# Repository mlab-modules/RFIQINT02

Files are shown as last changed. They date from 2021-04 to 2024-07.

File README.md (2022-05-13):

# RFIQINT02B -  RF signal I/Q interface

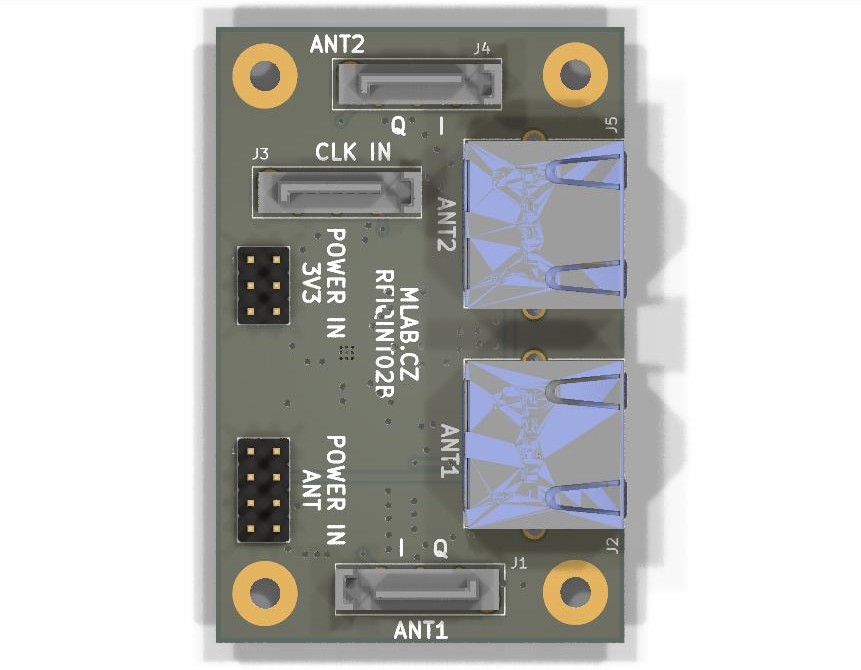
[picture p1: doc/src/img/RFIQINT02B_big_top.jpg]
RFIQINT02B PCB render


## Parameters

| Parameter | Value | Description |
|---|---|---|
| Frequency range | 100 - 1000 MHz |  |
| Interface | RJ45 | CAT 7/A cable is expected |
| Operating and storage temperature | -20 - +30°C |  |
| Operational input voltage for Antenna | 9 - 12 V |  |
| Operational input voltage  | 3.3-3.6 V | 130 mA for LO buffer core |

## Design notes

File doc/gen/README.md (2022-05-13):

# PCB

Board size: 40.13x60.45 mm (1.58x2.38 inches)

- This is the size of the rectangle that contains the board
- Thickness: 1.6 mm (63 mils)
- Material: FR4
- Finish: None
- Layers: 2
- Copper thickness: 35 µm

Solder mask: TOP / BOTTOM

- Color: Green

Silk screen: TOP / BOTTOM

- Color: White

Stackup:

| Name | Type | Color | Thickness | Material | Epsilon_r | Loss tangent |
|---|---|---|---|---|---|---|
| F.SilkS | Top Silk Screen | | | | | |
| F.Paste | Top Solder Paste | | | | | |
| F.Mask | Top Solder Mask | Green | 10 | | | |
| F.Cu | copper | | 35 | | | |
| dielectric 1 | core | | 1510 | FR4 | 4.5 | 0.02 |
| B.Cu | copper | | 35 | | | |
| B.Mask | Bottom Solder Mask | Green | 10 | | | |
| B.Paste | Bottom Solder Paste  | | | | | |
| B.SilkS | Bottom Silk Screen | | | | | |

# Important sizes

Clearance: 0.2 mm (8 mils)

Track width: 0.2 mm (8 mils)

- By design rules: 0.15 mm (6 mils)

Drill: 0.3 mm (12 mils)

- Vias: 0.4 mm (16 mils) [Design: 0.3 mm (12 mils)]
- Pads: 0.3 mm (12 mils)

Via: 0.8/0.4 mm (31/16 mils)

- By design rules: 0.4/0.3 mm (16/12 mils)
- Micro via: no [0.2/0.1 mm (8/4 mils)]
- Burried/blind via: no

Outer Annular Ring: 0.2 mm (8 mils)

- By design rules: 0.3 mm (12 mils)

Eurocircuits class: 4C

# General stats

Components count: (SMD/THT)

- Top: 0/9 (THT)
- Bottom: 35/2 (SMD + THT)

Defined tracks:

- 0.15 mm (6 mils)
- 0.2 mm (8 mils)
- 0.3 mm (12 mils)
- 0.4 mm (16 mils)
- 0.5 mm (20 mils)

Used tracks:

- 0.2 mm (8 mils) (22) defined: yes
- 0.3 mm (12 mils) (290) defined: yes
- 0.4 mm (16 mils) (28) defined: yes
- 0.5 mm (20 mils) (30) defined: yes
- 0.7 mm (28 mils) (26) defined: no

Defined vias:

Used vias:

- 0.8/0.4 mm (31/16 mils) (Count: 5, Aspect: 2.0 A) defined: no
- 0.8/0.6 mm (31/24 mils) (Count: 73, Aspect: 2.0 A) defined: no

Holes (excluding vias):

- 0.3 mm (12 mils) (9)
- 0.74 mm (29 mils) (21)
- 0.89 mm (35 mils) (14)
- 0.93 mm (37 mils) (24)
- 1.35 mm (53 mils) (6)
- 1.65 mm (65 mils) (4)
- 3.0 mm (118 mils) (4)
- 3.3 mm (130 mils) (4)

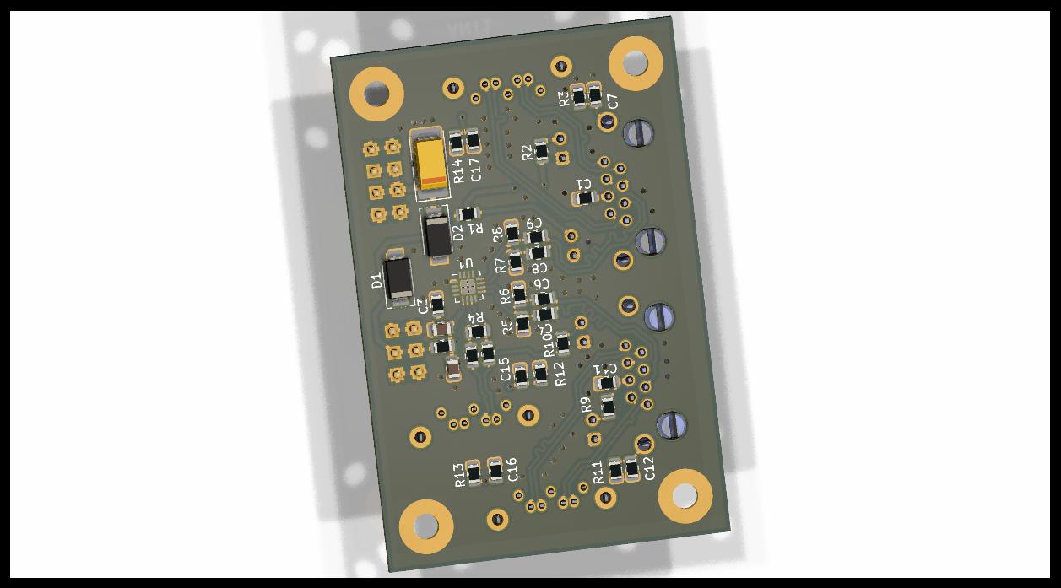
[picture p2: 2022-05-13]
doc/src/img/RFIQINT02B_big_bot.jpg

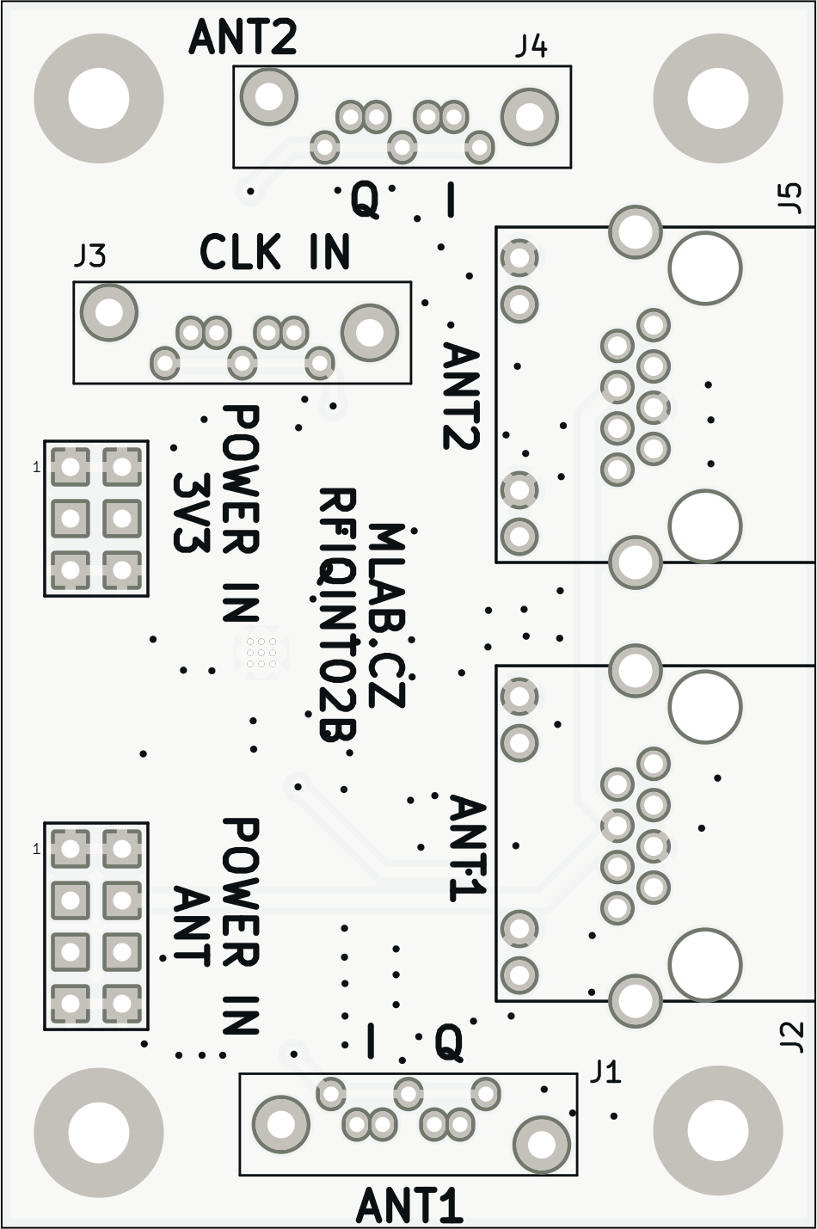
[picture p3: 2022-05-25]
doc/gen/img/RFIQINT02B-top.png

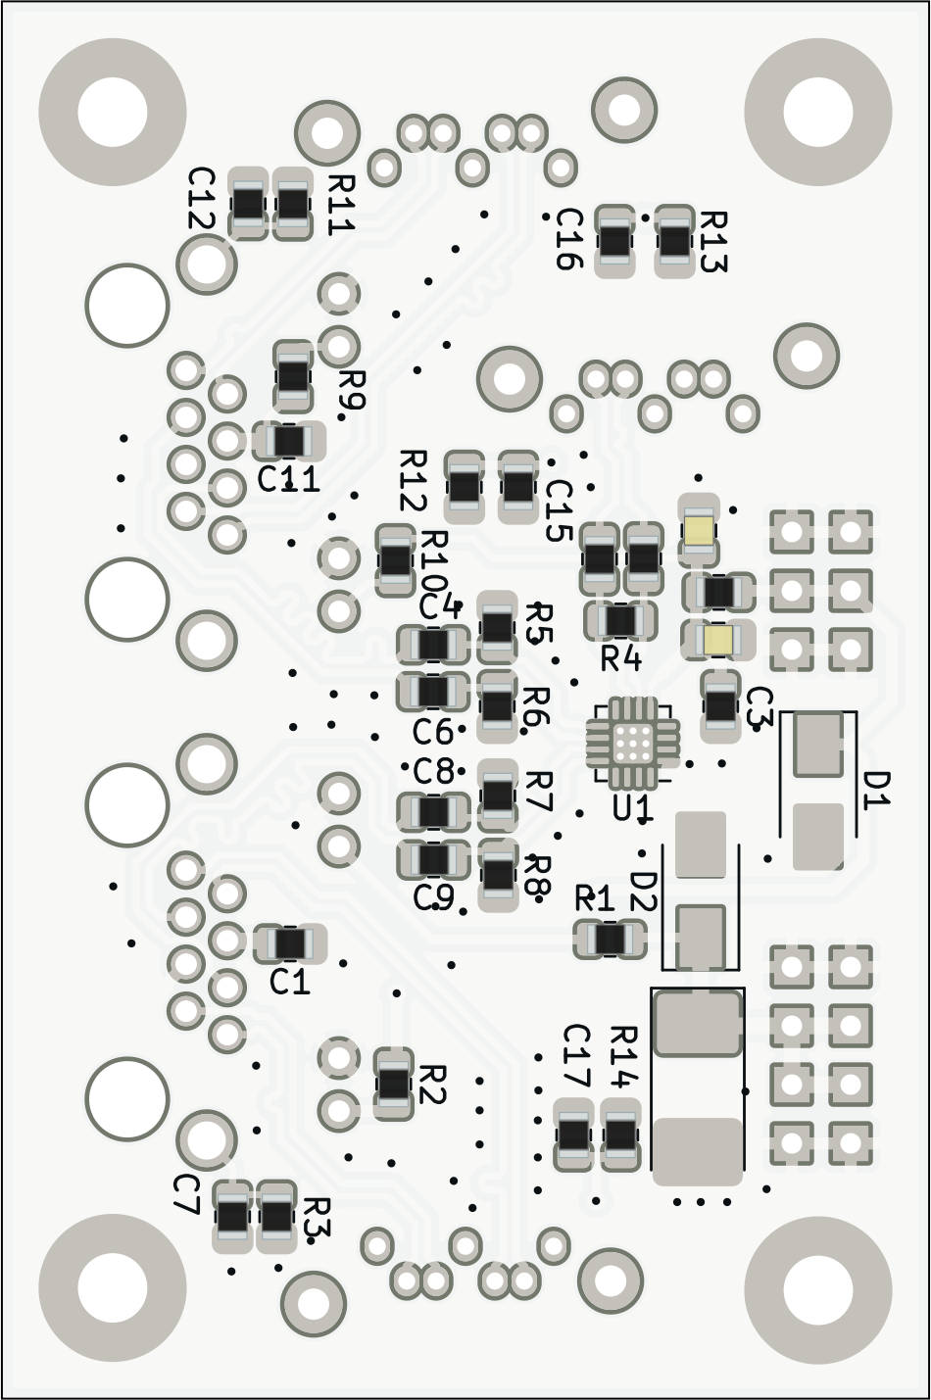
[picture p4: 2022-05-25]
doc/gen/img/RFIQINT02B-bottom.png

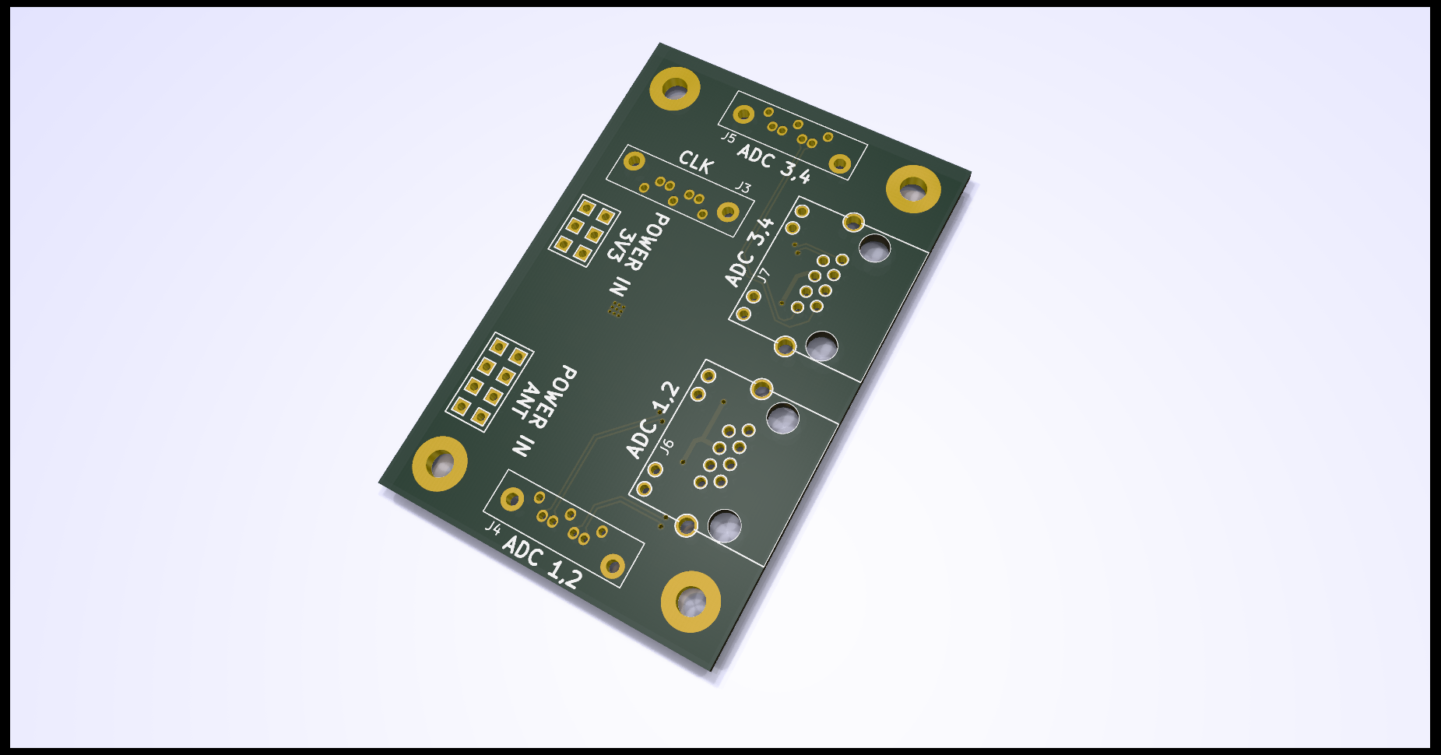
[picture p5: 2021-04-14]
doc/src/img/RFIQINT02A_PCB_render.png

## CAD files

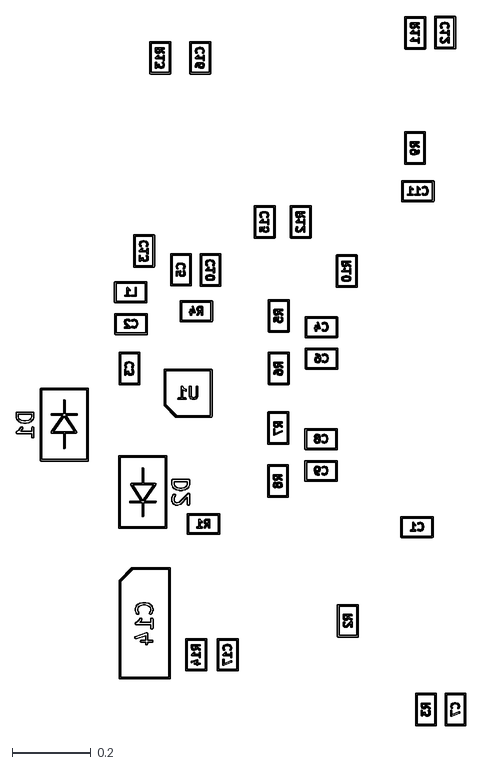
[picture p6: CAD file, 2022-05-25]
doc/gen/dxf/RFIQINT02B-B_Fab.dxf
1.15 x 1.81

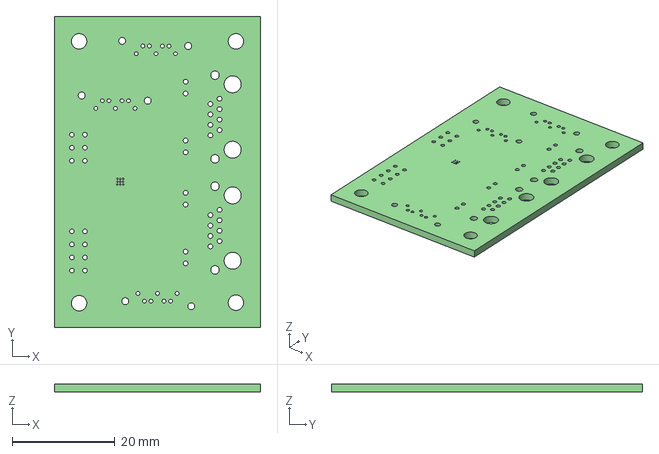
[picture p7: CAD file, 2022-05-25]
doc/gen/RFIQINT02B.step
40.1 x 60.5 x 1.60 mm

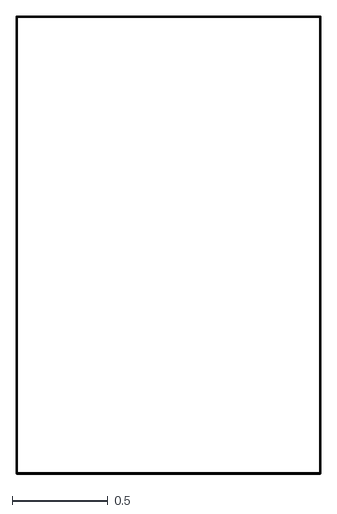
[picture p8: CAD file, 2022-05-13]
doc/gen/dxf/RFIQINT02B-Edge_Cuts.dxf
1.59 x 2.39

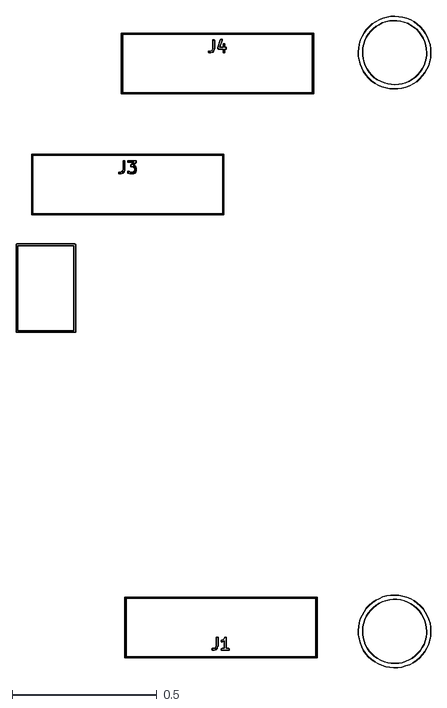
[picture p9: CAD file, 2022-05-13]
doc/gen/dxf/RFIQINT02B-F_Fab.dxf
1.43 x 2.25

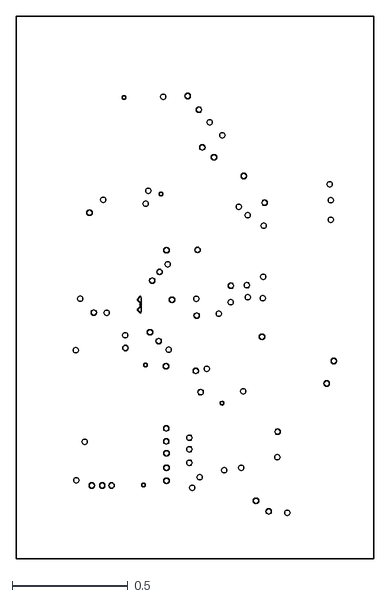
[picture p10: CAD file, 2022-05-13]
doc/gen/dxf/RFIQINT02B-F_Cu.dxf
1.54 x 2.34

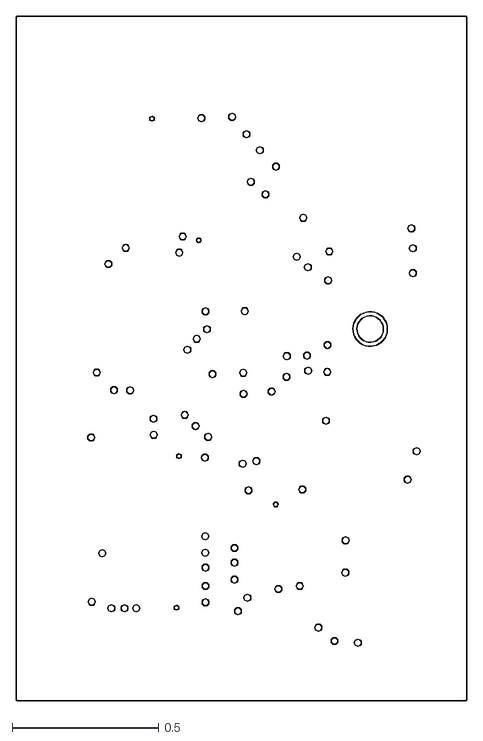
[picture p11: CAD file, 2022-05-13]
doc/gen/dxf/RFIQINT02B-B_Cu.dxf
1.54 x 2.34

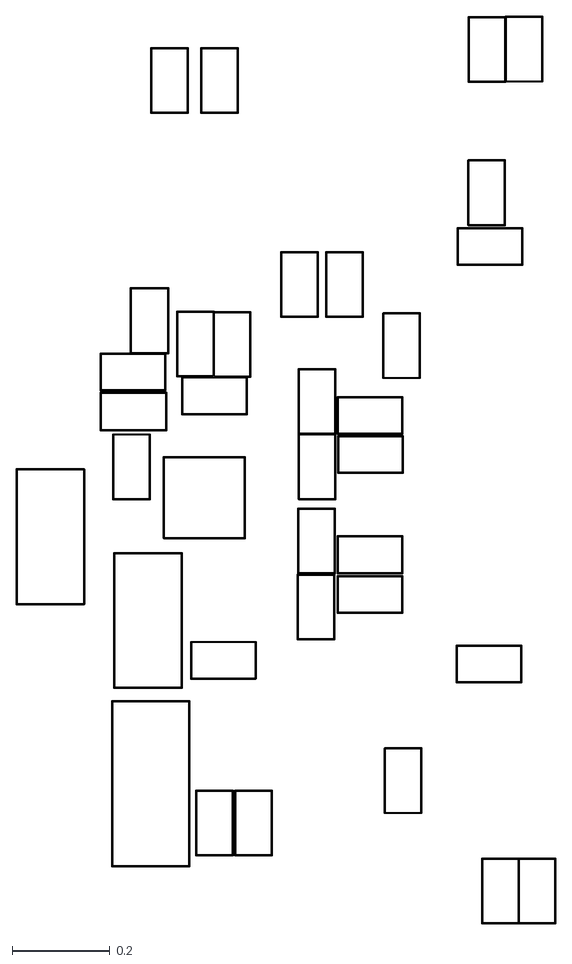
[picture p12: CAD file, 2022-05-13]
doc/gen/dxf/RFIQINT02B-B_Courtyard.dxf
1.10 x 1.86

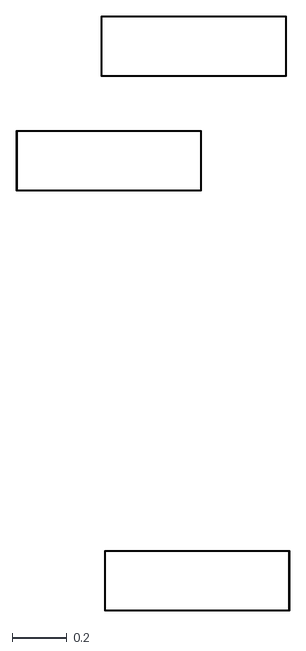
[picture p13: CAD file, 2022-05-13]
doc/gen/dxf/RFIQINT02B-F_Courtyard.dxf
0.997 x 2.17

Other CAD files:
doc/gen/dxf/RFIQINT02B-Margin.dxf
doc/gen/dxf/RFIQINT02B-B_Mask.dxf
doc/gen/dxf/RFIQINT02B-B_Paste.dxf
doc/gen/dxf/RFIQINT02B-B_Silkscreen.dxf
doc/gen/dxf/RFIQINT02B-F_Mask.dxf
doc/gen/dxf/RFIQINT02B-F_Paste.dxf
doc/gen/dxf/RFIQINT02B-F_Silkscreen.dxf

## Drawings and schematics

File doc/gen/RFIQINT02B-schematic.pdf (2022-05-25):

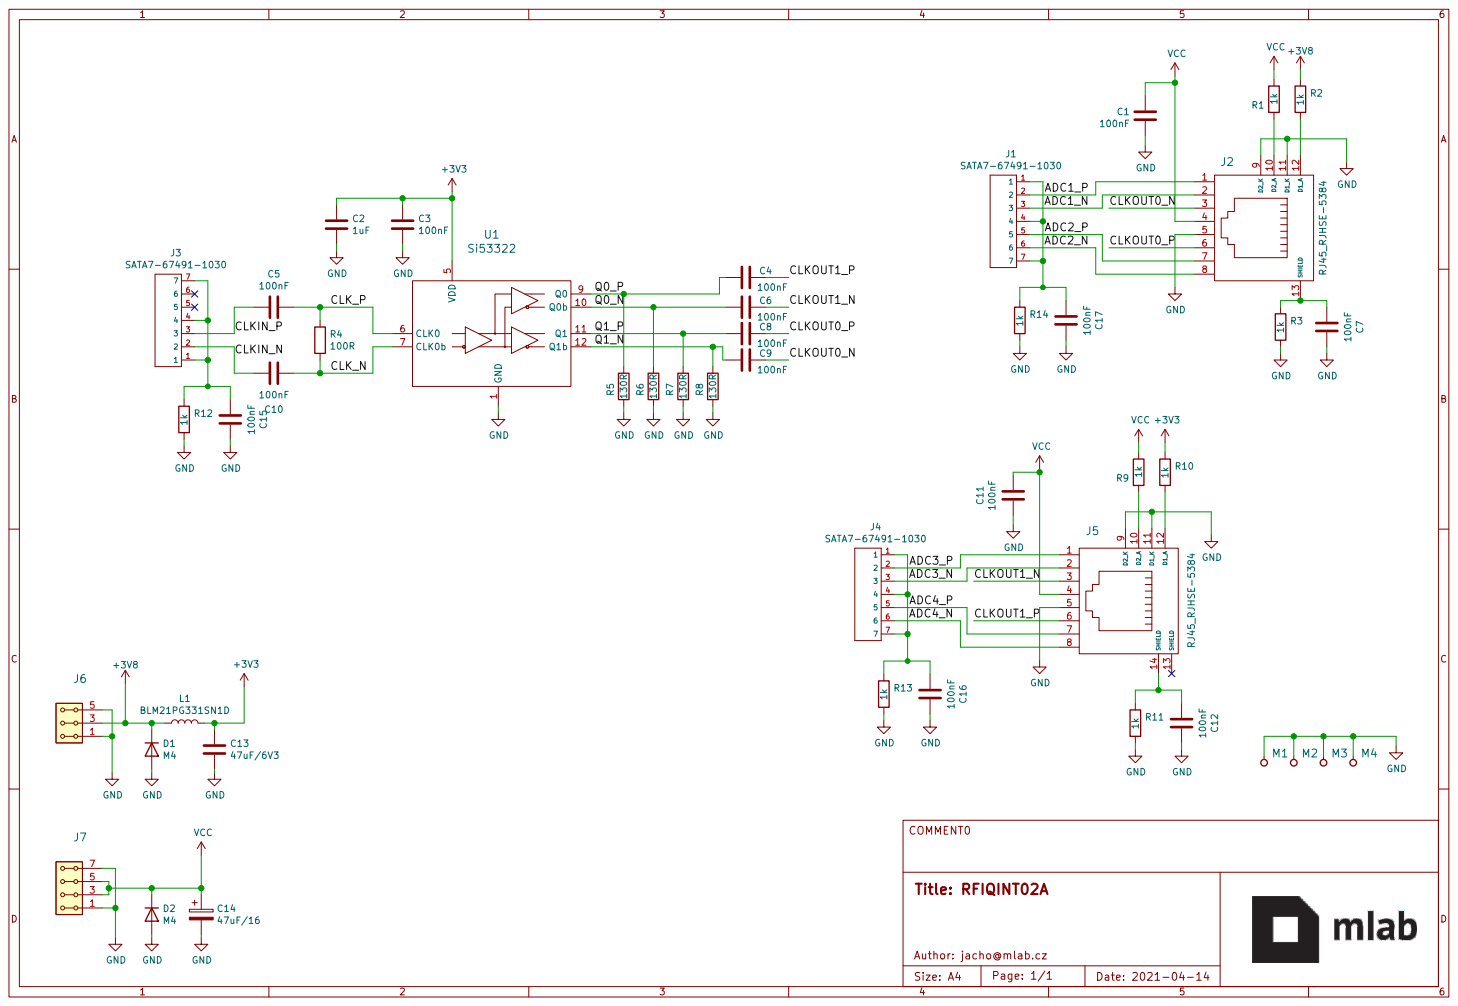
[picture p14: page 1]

3 | ADC3_N | CLKOUT1_N | 3
4 | ADC4_P | | 4

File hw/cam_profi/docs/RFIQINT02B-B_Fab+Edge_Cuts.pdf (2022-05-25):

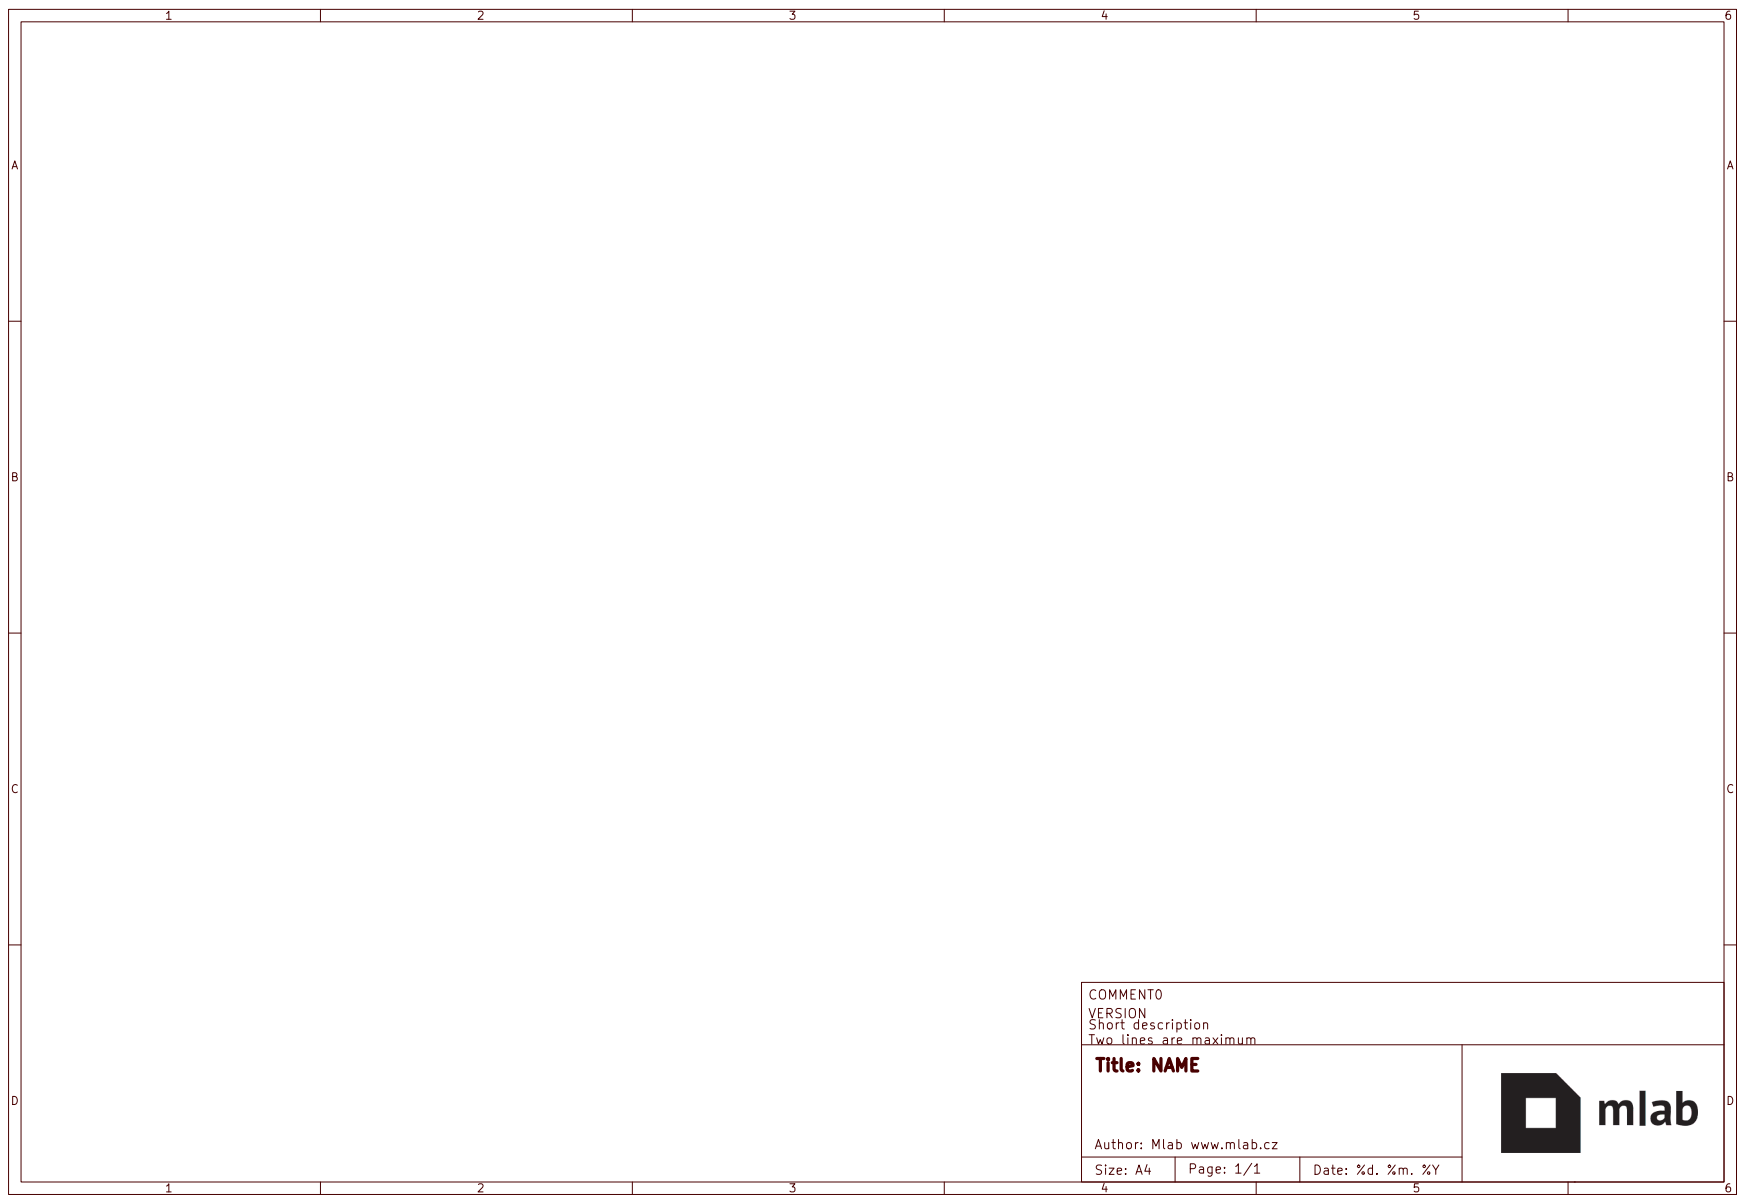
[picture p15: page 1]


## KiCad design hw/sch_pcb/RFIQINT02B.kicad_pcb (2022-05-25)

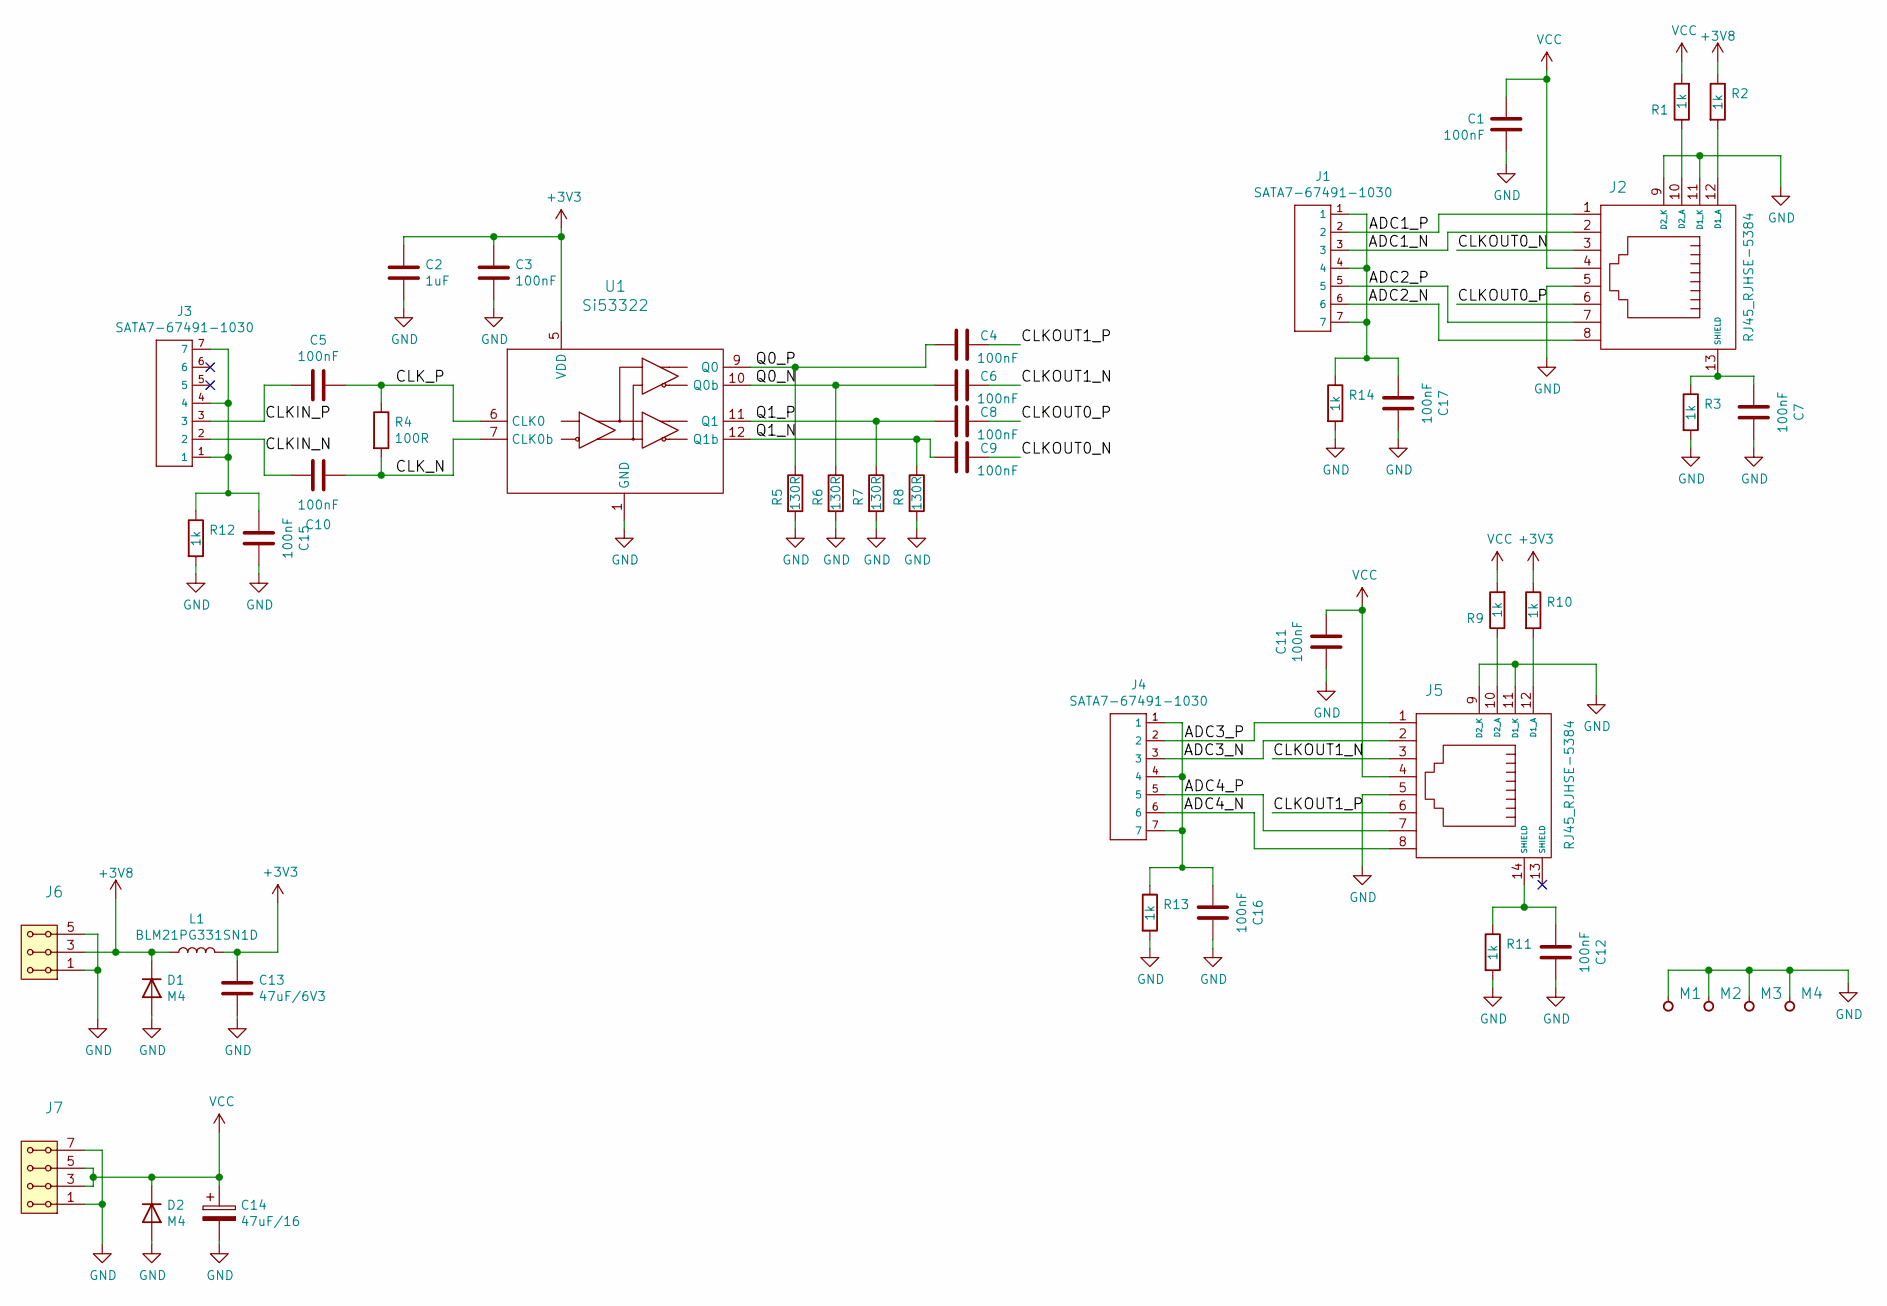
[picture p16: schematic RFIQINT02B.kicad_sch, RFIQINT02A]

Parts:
C1, C3, C4, C5, C6, C7, C8, C9, C10, C11, C12, C15, C16, C17: 100nF; R_0805_2012Metric
C2: 1uF; C_0805_2012Metric
C13: 47uF/6V3; C_0805_2012Metric
C14: 47uF/16; CP_EIA-7132-28_AVX-C
D1, D2: M4; D_SMA
J1, J3, J4: SATA7-67491-1030; SATA-7_THT_VERT_2
J2, J5: RJ45_RJHSE-5384; RJHSE-5384(RJ45)
J6: HEADER_2x03_PARALLEL; Straight_2x03
J7: HEADER_2x04_PARALLEL; Straight_2x04
L1: BLM21PG331SN1D; R_0805_2012Metric
M1, M2, M3, M4: HOLE; MountingHole_3mm
R1, R2, R3, R9, R10, R11, R12, R13, R14: 1k; R_0805_2012Metric
R4: 100R; R_0805_2012Metric
R5, R6, R7, R8: 130R; R_0805_2012Metric
U1: Si53322; QFN-16-1EP_3x3mm_P0.5mm_EP1.7x1.7mm_ThermalVias

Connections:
+3V3: C2.1, C3.1, C13.1, L1.2, R10.1, U1.5 (VDD)
+3V8: D1.1 (K), J6.3, J6.4, L1.1, R2.1
/ADC1_N: J1.3, J2.2
/ADC1_P: J1.2, J2.1
/ADC2_N: J1.6, J2.8
/ADC2_P: J1.5, J2.7
/ADC3_N: J4.3, J5.2
/ADC3_P: J4.2, J5.1
/ADC4_N: J4.6, J5.8
/ADC4_P: J4.5, J5.7
/CLKIN_N: C10.1, J3.2
/CLKIN_P: C5.1, J3.3
/CLKOUT0_N: C9.2, J2.3
/CLKOUT0_P: C8.2, J2.6
/CLKOUT1_N: C6.2, J5.3
/CLKOUT1_P: C4.2, J5.6
/CLK_N: C10.2, R4.2, U1.7 (CLK0b)
/CLK_P: C5.2, R4.1, U1.6 (CLK0)
/Q0_N: C6.1, R6.1, U1.10 (Q0b)
/Q0_P: C4.1, R5.1, U1.9 (Q0)
/Q1_N: C9.1, R8.1, U1.12 (Q1b)
/Q1_P: C8.1, R7.1, U1.11 (Q1)
GND: C1.1, C2.2, C3.2, C7.2, C11.1, C12.2, C13.2, C14.2, C15.2, C16.2, C17.2, D1.2 (A), D2.2 (A), J2.5, J2.9 (D2_K), J2.11 (D1_K), J5.5, J5.9 (D2_K), J5.11 (D1_K), J6.1, J6.2, J6.5, J6.6, J7.1, J7.2, J7.7, J7.8, M1.1, M2.1, M3.1, M4.1, R3.2, R5.2, R6.2, R7.2, R8.2, R11.2, R12.2, R13.2, R14.2, U1.1 (GND), U1.17 (GND)
unnamed: C7.1, J2.13 (SHIELD), R3.1
unnamed: C12.1, J5.14 (SHIELD), R11.1
unnamed: C17.1, J1.1, J1.4, J1.7, R14.1
unnamed: J2.10 (D2_A), R1.1
unnamed: J2.12 (D1_A), R2.2
unnamed: C15.1, J3.1, J3.4, J3.7, R12.1
unnamed: C16.1, J4.1, J4.4, J4.7, R13.1
unnamed: J5.10 (D2_A), R9.1
unnamed: J5.12 (D1_A), R10.2
VCC: C1.2, C11.2, C14.1, D2.1 (K), J2.4, J5.4, J7.3, J7.4, J7.5, J7.6, R1.2, R9.2

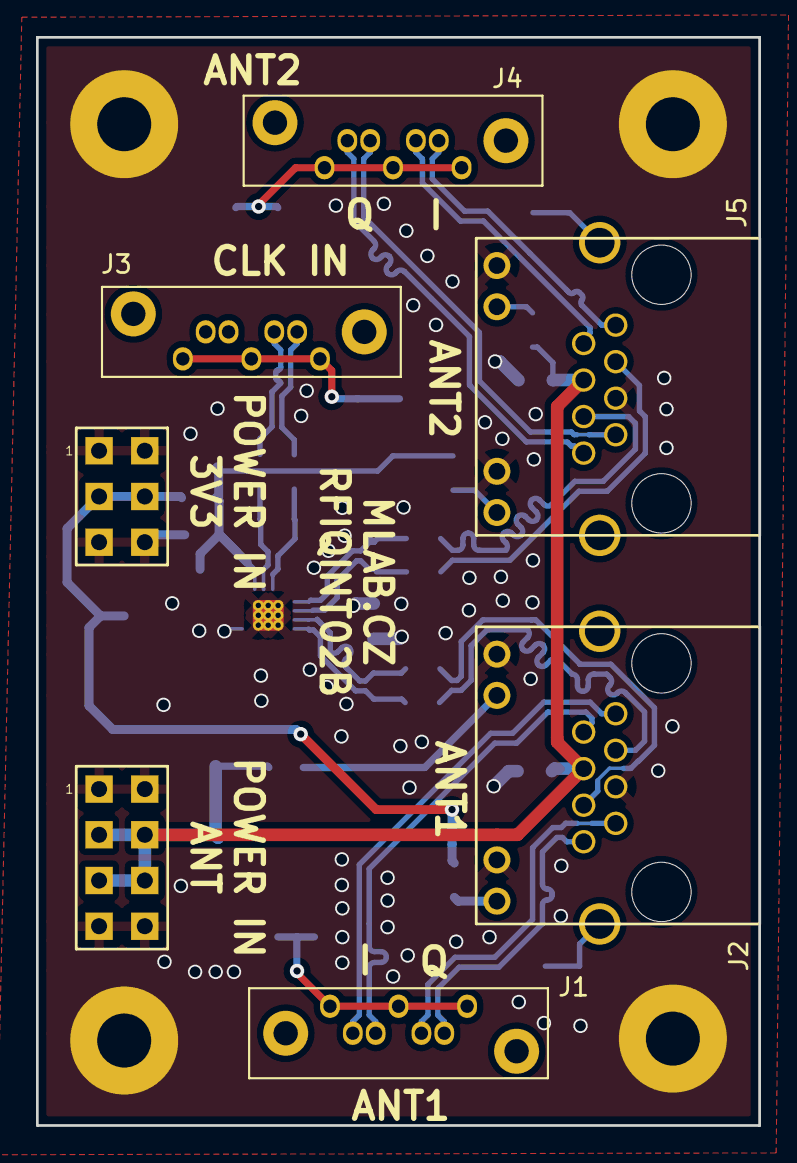
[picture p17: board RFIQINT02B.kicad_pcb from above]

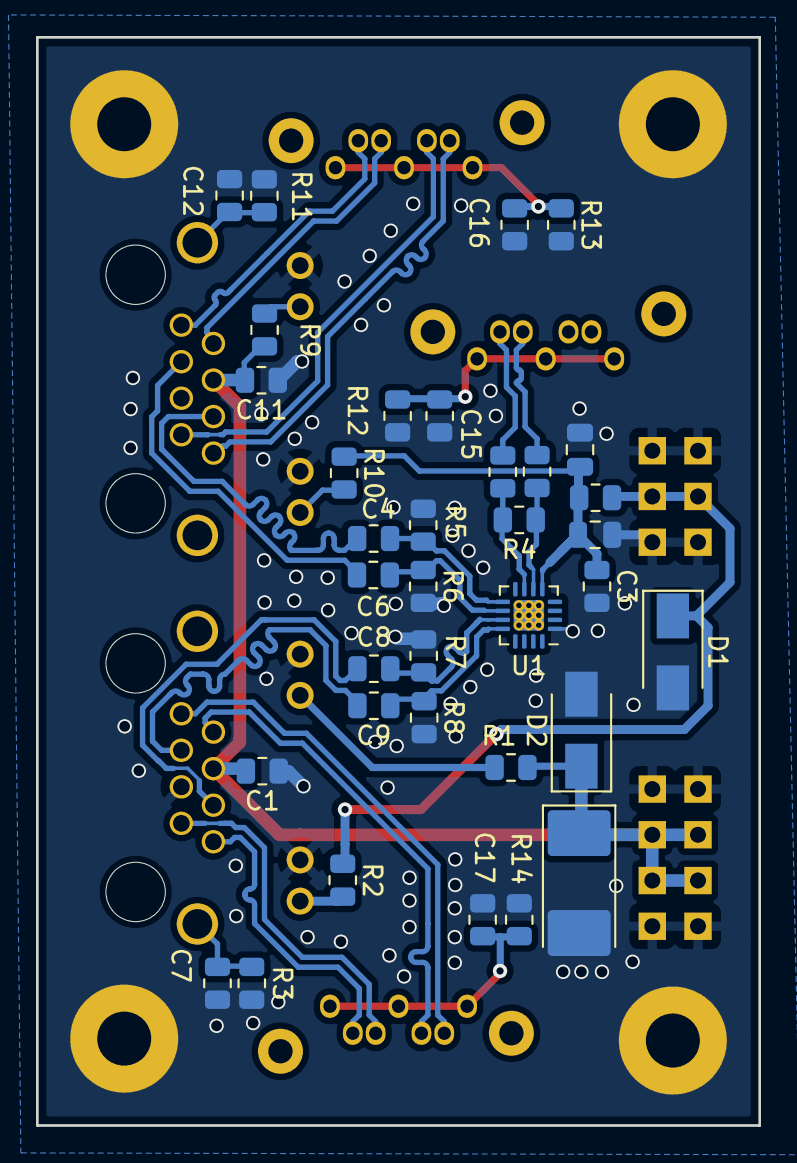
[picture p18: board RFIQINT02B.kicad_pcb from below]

Board: 2 copper layers, 40.1 x 60.5 mm, 46 parts (37 on the bottom side), 33 nets.

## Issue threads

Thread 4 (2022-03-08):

Revize modulu

ChroustJan, 2022-03-08:
@kaklik bude se na modulu něco upravovat?

ChroustJan, 2022-05-13:
Bude napájeno z BATPOWER04C

kaklik, 2022-05-13:
> Bude napájeno z BATPOWER04C

To nejde, ten ruší.

ChroustJan, 2022-05-13:
@kaklik tím pádem máme problém a není vyřešené kompletně blokové schéma bleskodetektoru.

ChroustJan, 2022-05-13:
Modul je to tento: [BATPOWER05A](https://github.com/MLAB-project/Modules/tree/master/power_supply/BATPOWER05A)

kaklik, 2022-05-13:
> Modul je to tento: [BATPOWER05A](https://github.com/MLAB-project/Modules/tree/master/power_supply/BATPOWER05A)

A existuje od tohoto modulu nějaká alternativa, která je nyní v produkci?  Pokud žádný takový alternativní měnič nyní není, tak zřejmě nezbývá nic jiného, než použít 3.3V z lineárního stabilizátoru na některém z ostatních modulů.

Closed 2022-08-25.

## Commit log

2020-08-10 Tvorba schema a PCB
    [RFIQINT02A.kicad_pcb, RFIQINT02A.kicad_sch, RFIQINT02A.sch]
2020-09-21 Edit PCB
    [RFIQINT02A.kicad_pcb, RFIQINT02A.kicad_sch]
2020-11-02 Test of differential pair skew tune.
    [RFIQINT02A.kicad_pcb]
2021-04-14 Improve documentation. Generate new image. Remove irrelavant symbols in silkscreen.
    [RFIQINT02A.kicad_pcb, RFIQINT02A.kicad_sch]
2021-06-17 Edit UST ID
    [RFIQINT02A.csv, RFIQINT02A.kicad_sch]
2021-06-18 Update project and title block.
    [RFIQINT02A.kicad_sch, RFIQINT02A.sch]
2021-06-18 remove vias from differential pairs routing.
    [RFIQINT02A.kicad_pcb, RFIQINT02A.kicad_sch]
2021-06-18 Update net classes.
    [RFIQINT02A.kicad_pcb]
2021-06-18 Apply net class parameters.
    [RFIQINT02A.kicad_pcb]
2021-06-21 Tune skew of differential pairs.
    Use the RJ45 connector's LED as power indicators.
    [RFIQINT02A.kicad_pcb, RFIQINT02A.kicad_sch]
2021-06-22 Add grounding vias remove thermal relief at U1 grounding. #3.
    [RFIQINT02A.kicad_pcb]
2021-06-23 Generating production data
    [RFIQINT02A-B_Cu.gbr, RFIQINT02A-B_Mask.gbr, RFIQINT02A-Edge_Cuts.gbr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]
2021-06-30 Edit B.FAB
    [RFIQINT02A.kicad_pcb]
2021-07-01 New bom
    [RFIQINT02A.csv]
2022-03-08 Update to KiCAD version 6.0.
    [RFIQINT02A.kicad_pcb, RFIQINT02A.kicad_sch]
2022-05-13 Renaming KiCad projekt
    [RFIQINT02A.csv, RFIQINT02B.kicad_pcb, RFIQINT02B.kicad_sch]
2022-05-13 #6 #5
    [RFIQINT02B.kicad_pcb, RFIQINT02B.kicad_sch]
2022-05-13 Update actions products
    [RFIQINT02B-B_Courtyard.dxf, RFIQINT02B-B_Cu.dxf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]
2022-05-25 Editace podkladů po osazení
    [RFIQINT02B.kicad_pcb]
